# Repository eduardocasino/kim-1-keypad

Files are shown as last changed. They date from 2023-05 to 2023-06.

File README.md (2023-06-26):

# KIM-1 Keypad

## About

Welcome to the KIM-1 Keypad repository.

I designed this board for [my KIM-1 PCB replica](https://github.com/eduardocasino/kim-1), but it will also work with real KIM-1s from Revision D and onwards.

~~WARNING: I have not yet sent the board to fabrication, so it is untested!~~

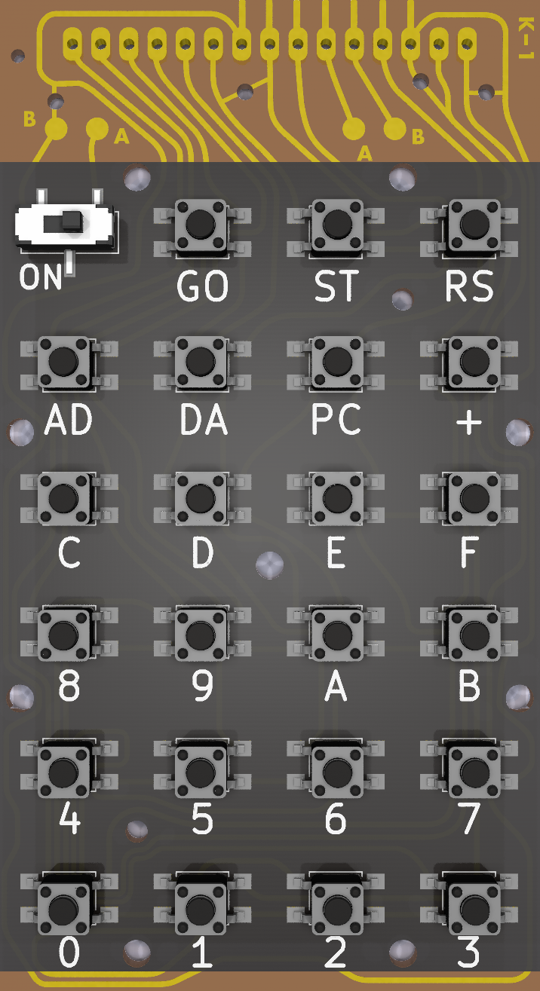
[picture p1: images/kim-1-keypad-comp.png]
components


## Licensing

This is a personal project that I am sharing in case it is of interest to any retrocomputing enthusiast and all the information in this repository is provided "as is", without warranty of any kind. I am not liable for any damages that may occur, whether it be to individuals, objects, KIM-1 computers, kittens or any other pets. It should also be noted that this design has not been tested and may contain errors, therefore anyone who chooses to use it does so at their own risk.



This work is licensed under a [Creative Commons Attribution-NonCommercial 4.0 International License](http://creativecommons.org/licenses/by-nc/4.0/).

EXCEPTION: The electrical schematic and all the associated symbols are licensed under a [Creative Commons Attribution 4.0 International License](https://creativecommons.org/licenses/by/4.0/).

See the LICENSE.md file for details.

## Changelog
#### 05/06/2023
* Fix silkscreen and remove pads from bottom side
## Acknowledgements

* Hans Otten and his [Retro Computing blog](http://retro.hansotten.nl/). Tons of information and high resolution pictures of various KIM-1.
* Ralf (User ralf02 from forum64.de) for info on actual dimensions of the keypad and some high res photos.

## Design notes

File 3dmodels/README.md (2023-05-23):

Download the JS102011SCQN switch 3D model from [here](https://www.mouser.com/ProductDetail/CK/JS102011SCQN?qs=aIxPIZZxLh%2FC%2Fw7UJtfwsg%3D%3D) (Free registration required)

Make sure that the file is named JS102011SCQN.stp

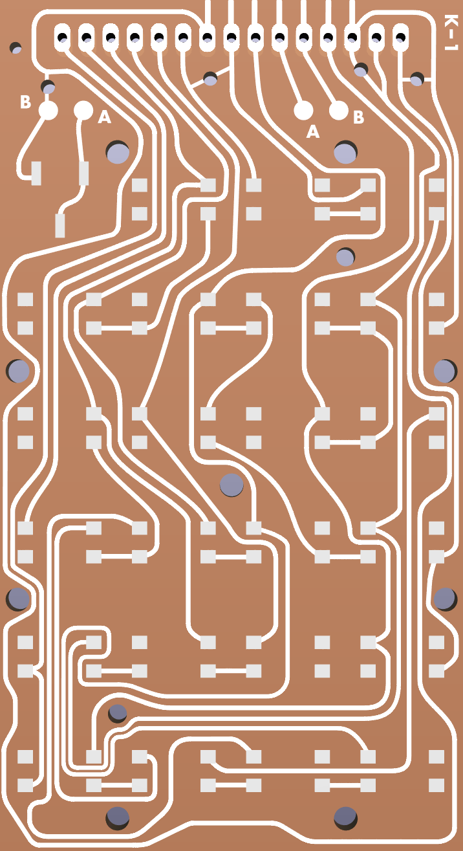
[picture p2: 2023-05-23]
images/kim-1-keypad-pcb.png

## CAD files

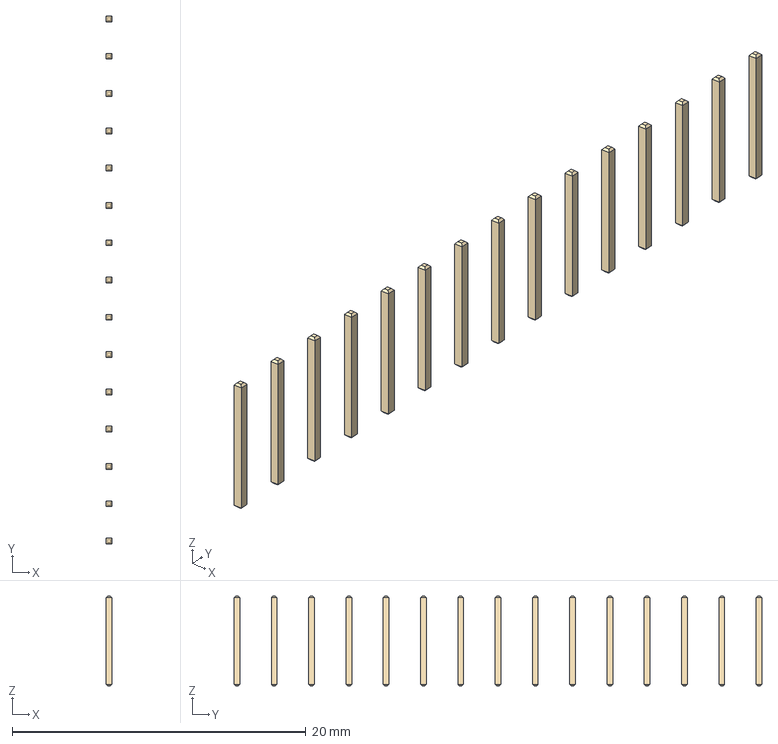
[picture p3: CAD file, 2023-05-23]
3dmodels/PinHeader_1x15_P2.54mm_Vertical.step
0.4 x 36.0 x 6.10 mm

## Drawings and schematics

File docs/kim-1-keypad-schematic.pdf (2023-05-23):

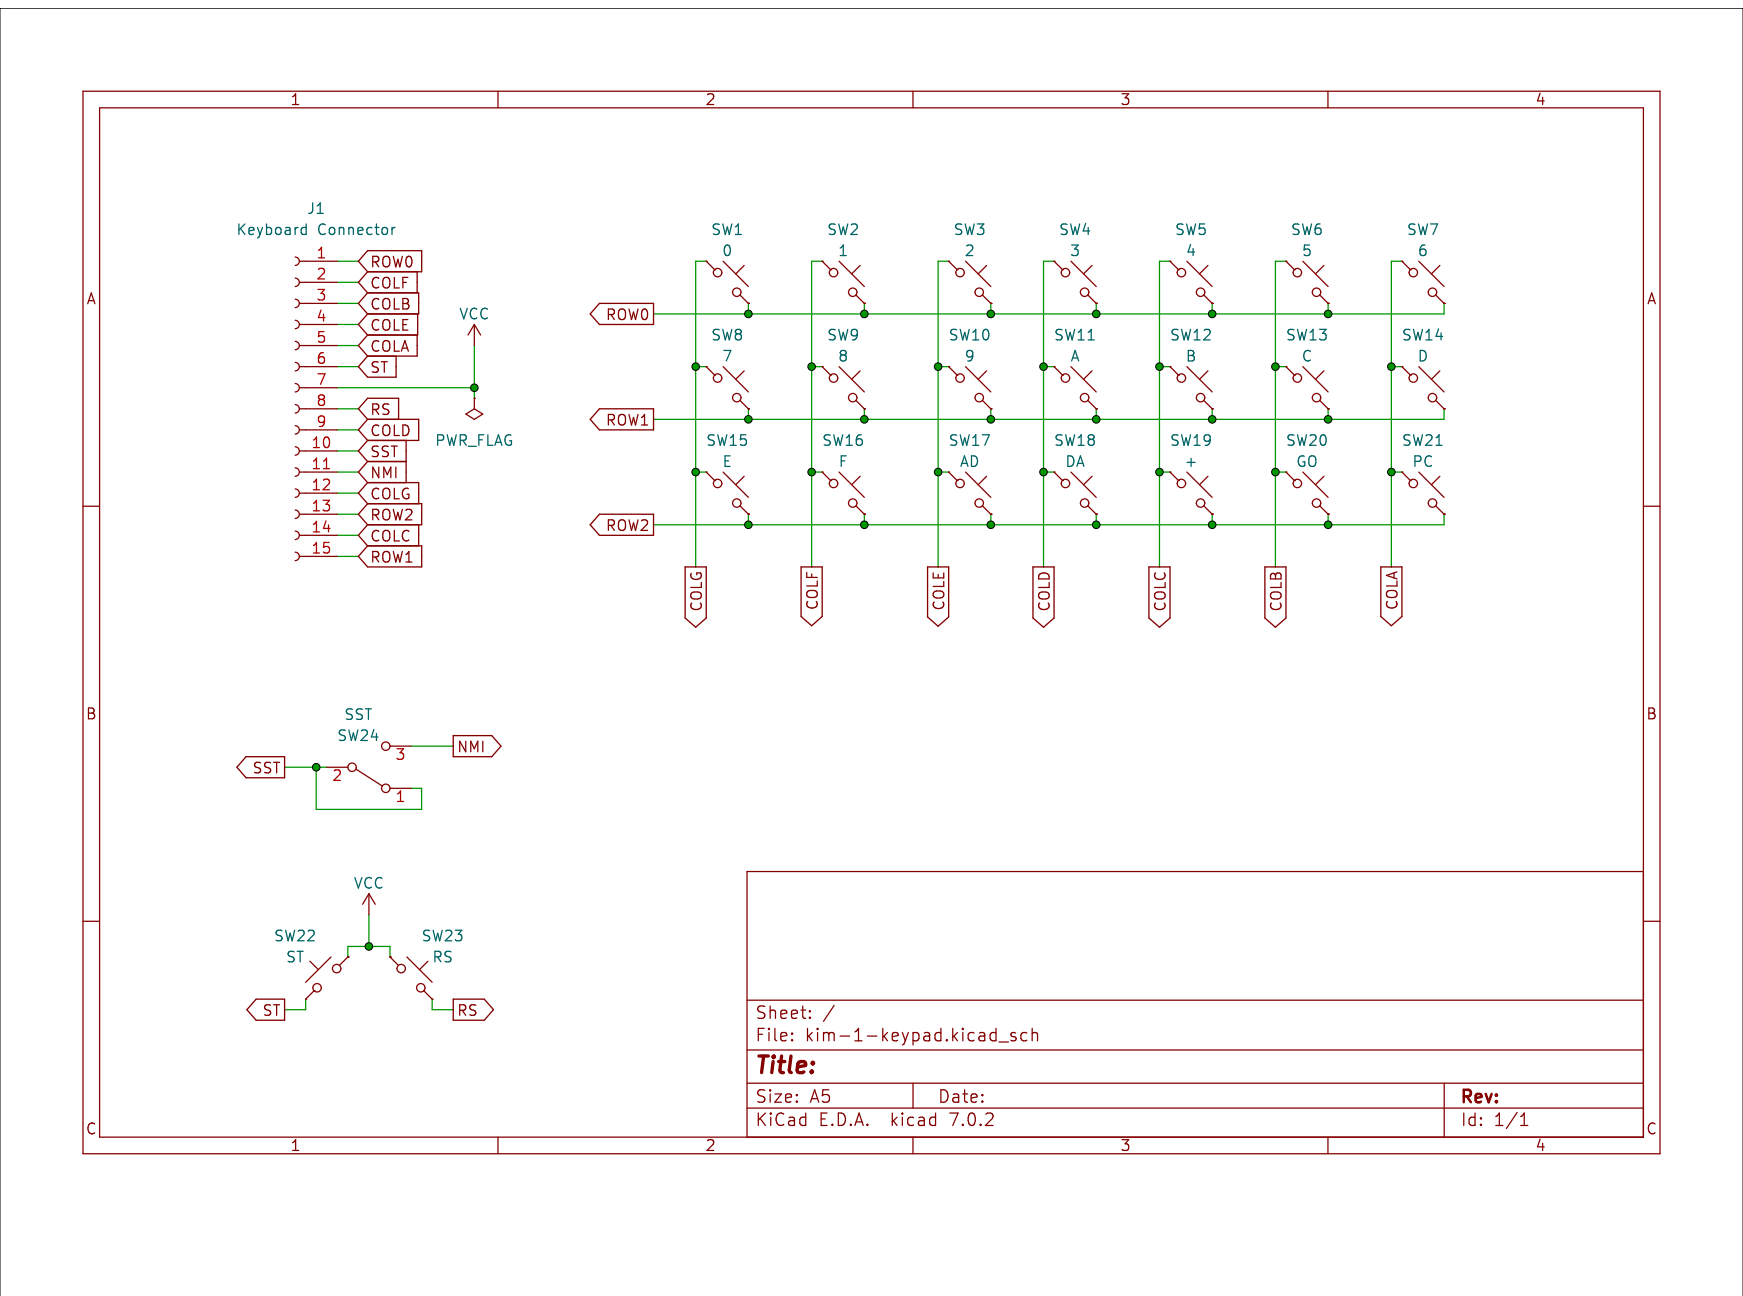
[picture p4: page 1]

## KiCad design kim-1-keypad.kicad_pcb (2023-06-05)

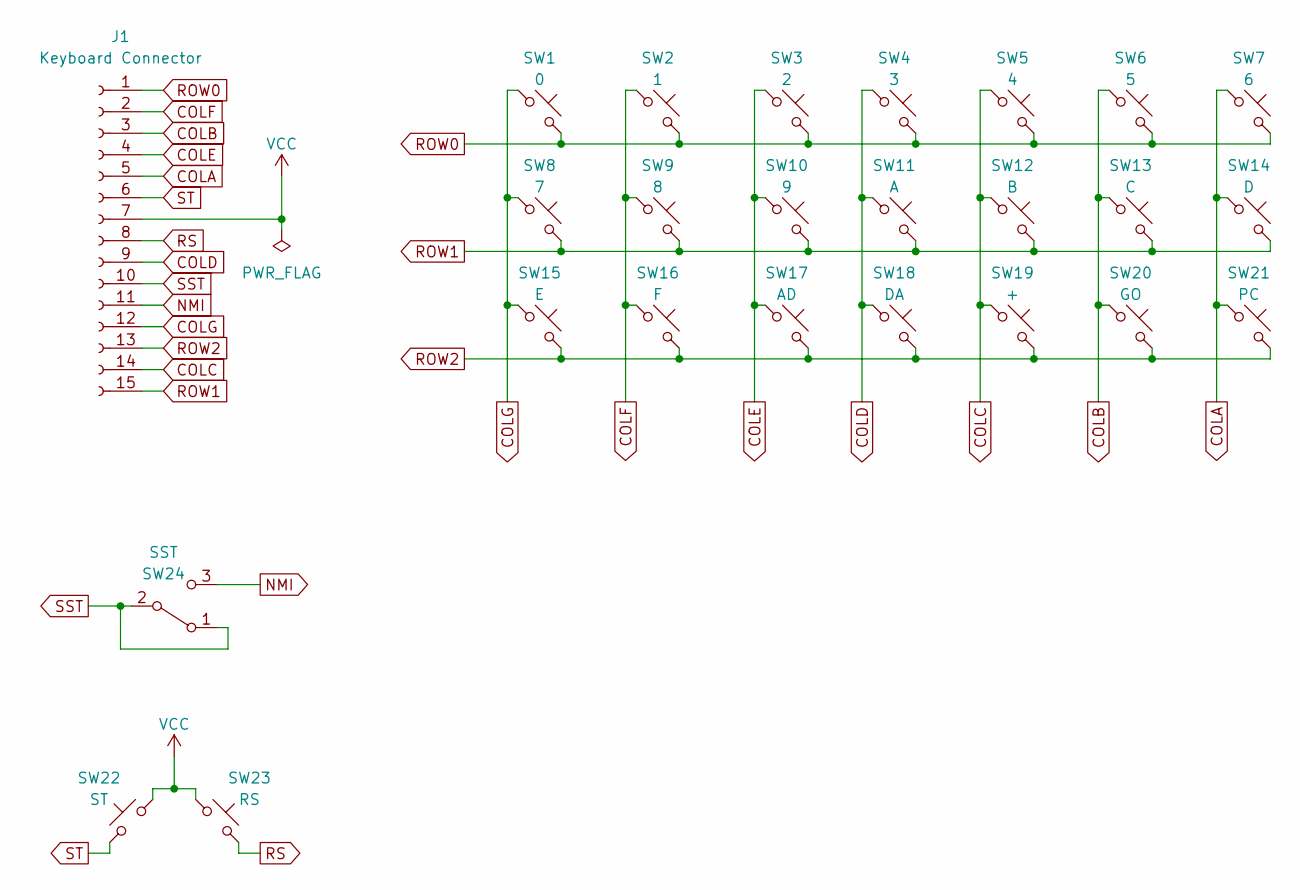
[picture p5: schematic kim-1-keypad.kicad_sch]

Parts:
J1: Keyboard Connector; PinHeader_1x15_P2.54mm_Vertical
SW1: 0; SW_SPST_TL3305A
SW2: 1; SW_SPST_TL3305A
SW3: 2; SW_SPST_TL3305A
SW4: 3; SW_SPST_TL3305A
SW5: 4; SW_SPST_TL3305A
SW6: 5; SW_SPST_TL3305A
SW7: 6; SW_SPST_TL3305A
SW8: 7; SW_SPST_TL3305A
SW9: 8; SW_SPST_TL3305A
SW10: 9; SW_SPST_TL3305A
SW11: A; SW_SPST_TL3305A
SW12: B; SW_SPST_TL3305A
SW13: C; SW_SPST_TL3305A
SW14: D; SW_SPST_TL3305A
SW15: E; SW_SPST_TL3305A
SW16: F; SW_SPST_TL3305A
SW17: AD; SW_SPST_TL3305A
SW18: DA; SW_SPST_TL3305A
SW19: +; SW_SPST_TL3305A
SW20: GO; SW_SPST_TL3305A
SW21: PC; SW_SPST_TL3305A
SW22: ST; SW_SPST_TL3305A
SW23: RS; SW_SPST_TL3305A
SW24: SST; JS102011SCQN

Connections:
COLA: J1.5, SW7.1, SW14.1, SW21.1
COLB: J1.3, SW6.1, SW13.1, SW20.1
COLC: J1.14, SW5.1, SW12.1, SW19.1
COLD: J1.9, SW4.1, SW11.1, SW18.1
COLE: J1.4, SW3.1, SW10.1, SW17.1
COLF: J1.2, SW2.1, SW9.1, SW16.1
COLG: J1.12, SW1.1, SW8.1, SW15.1
NMI: J1.11, SW24.3 (C)
ROW0: J1.1, SW1.2, SW2.2, SW3.2, SW4.2, SW5.2, SW6.2, SW7.2
ROW1: J1.15, SW8.2, SW9.2, SW10.2, SW11.2, SW12.2, SW13.2, SW14.2
ROW2: J1.13, SW15.2, SW16.2, SW17.2, SW18.2, SW19.2, SW20.2, SW21.2
RS: J1.8, SW23.1
SST: J1.10, SW24.1 (A), SW24.2 (B)
ST: J1.6, SW22.1
VCC: J1.7, SW22.2, SW23.2

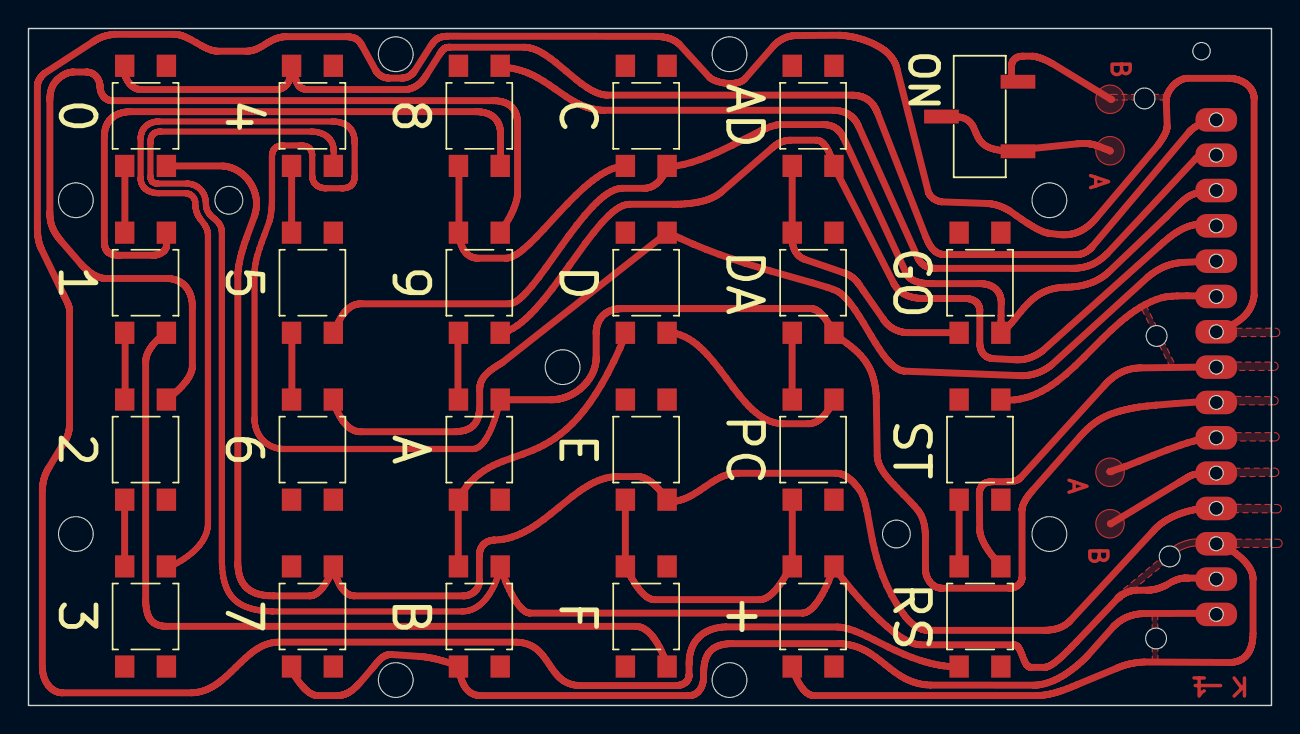
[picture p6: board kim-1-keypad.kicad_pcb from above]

Board: 2 copper layers, 89.4 x 48.7 mm, 41 parts (0 on the bottom side), 15 nets.

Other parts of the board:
H1, H2, H3, H4, H5, H6, H7, H8, H9#2: MountingHole_2.5mm
H9, H10: MountingHole_2mm
H11, H12, H13, H14: MountingHole_1.5mm
H11#2: MountingHole_1.25mm

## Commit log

2023-05-25 Generate correct gerber files format
    [kim-1-keypad-B_Cu.gbl, kim-1-keypad-B_Mask.gbs, kim-1-keypad-B_Paste.gbp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]
2023-06-05 Connector: Remove copper pads from botton side
2023-06-05 Fix silkscreen under slide switch
    [kim-1-keypad-F_Silkscreen.gto]
2023-06-05 Fix silkscreen and connector pads
    [kim-1-keypad.kicad_pcb]

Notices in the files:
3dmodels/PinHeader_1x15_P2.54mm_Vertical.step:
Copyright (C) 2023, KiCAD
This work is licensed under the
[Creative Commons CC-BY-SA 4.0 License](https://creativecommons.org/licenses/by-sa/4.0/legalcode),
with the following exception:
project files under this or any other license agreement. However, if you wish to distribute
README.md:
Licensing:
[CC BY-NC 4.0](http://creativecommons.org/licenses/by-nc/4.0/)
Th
